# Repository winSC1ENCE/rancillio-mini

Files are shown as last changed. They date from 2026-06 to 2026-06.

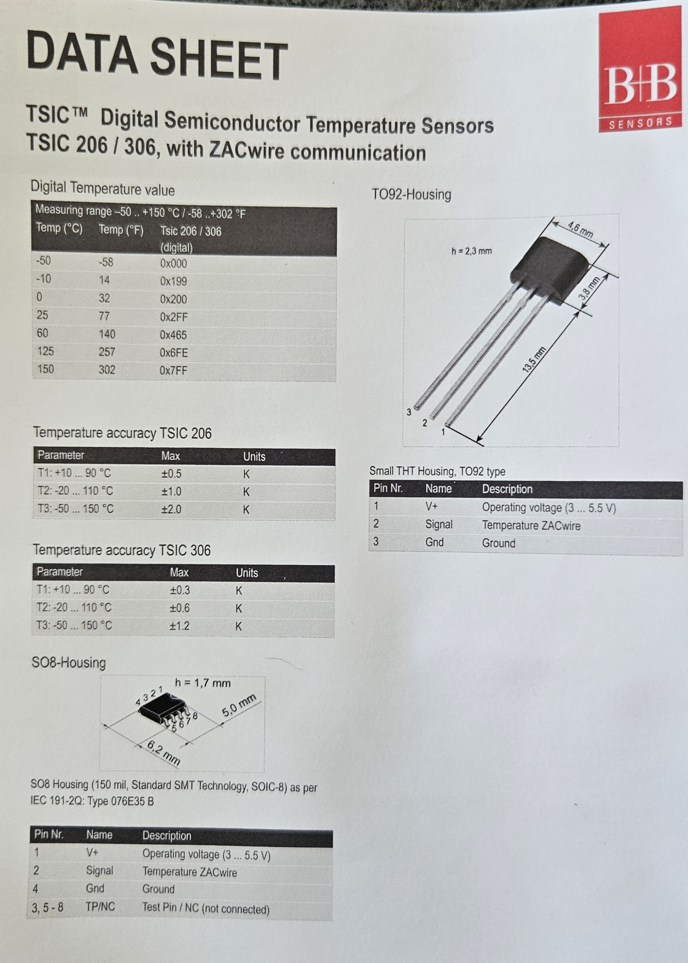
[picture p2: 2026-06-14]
docs/img/temp_sensor_datsheet.jpg

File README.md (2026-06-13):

# CleverCoffee
(formerly Rancilio PID)

<div align="center">

<br>
<a href='https://ko-fi.com/clevercoffee' target='_blank'>Buy Me a Coffee at ko-fi.com</a>
</div>

# About

This project implements a PID controller for stable and accurate temperature control, originally for Rancilio Silvia espresso machines but also includes support for Gaggia and Quickmill machines. Others can easily be added or are already compatible.

Additional features include:

* brew timer
* pre-infusion (reduced initial pressure using a dimmer for the pump)
* brew by weight (using weight cells, no support for external scales yet)
* pressure monitoring
* water level monitoring

The hardware has a small footprint and can easily fit also into most smaller espresso machines. The original wiring of the machine (mostly) remains and is only extended. The machine can be easily reversed to the orignal state after the conversion.

The project has been in active development and supported for 4 years with continuous improvements. Hundreds of machines have been converted to PID control already.

You can find our project website here: [Clever Coffee Website](https://clevercoffee.de).

This software is Open Source: free of charge for you and customizable to your personal needs. 

We recommend you to have a look at the manual before starting a build, you can find the german one [here](https://rancilio-pid.github.io/ranciliopid-handbook/). It is currently being reworked to include all the latest features. The english one is sadly still very outdated but will also be updated soon. 

Our chat for collaboration and questions can be found[here](https://chat.rancilio-pid.de).

Video tutorial on how to flash the firmware (a little outdated but mostly still valid):<br>
https://youtu.be/KZPjisOEcQ4

## Version
ESP8266 Version 3.3.0

## What is possible after installation into your espresso machine? 
 * Control of the brewing temperature with an accuracy of up to +/- 0,1°.
 * Reach the target temperature within 8 to 12 minutes after switching on (you should however wait a bit longer, e.g. 20 min depending on the machine to heat up brew head etc.)
 * **NEW** Control all parameters and see temperature and heater graphs on a web page hosted on the ESP controller
 * PID for steam mode with own parameters and target temperature (can be enabled in the web interface/MQTT or using the steam switch when all features are built in) 
 * Control the brewing time (including pre-infusion) when all features are built in.
 * Integration of a scale function, allows brewing by weight.
 * Integration of a water level sensor.
 * Multiple designs for the display, possibility to integrate further designs easily (including vertical template)
 * **NEW** MQTT (IoT) support to manipulate all important parameters.
 * **NEW** Transition from steam mode to normal mode optimized.
 * Brew switch detection also supported using an optocoupler when using OnlyPID ([details](https://rancilio-pid.github.io/ranciliopid-handbook/de/customization/brueherkennung.html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)).
 * Shot timer adjustable to see the reference time.
 * Support for Siliva E machines: trigger with definable interval for a relay to bypass the Eco function
 * Extended data monitoring via Influxdb/Grafana.
 * Over-The-Air updates of the firmware are possible via Wifi

User feedback and suggestions for further development of the software are most welcome.
You are welcome to help us in our mission to make better espresso :)

Thanks to every single supporter!

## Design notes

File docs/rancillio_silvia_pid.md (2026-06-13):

# Rancillio Silvia PID 

## Original Github Projekt 
- https://github.com/rancilio-pid/clevercoffee

## Platine
- https://manual.rancilio-pid.de/de/platinen/ESP8266.html#pin-belegung-vom-pcb-esp8266
- Ich habe aktuell die Platine für den ESP8266 in der Version Rev 1.2 

## Handbuch
- https://manual.rancilio-pid.de/de/

# Materialliste Aktuell
- Platine Rev 1.2 
- Microcontroller AZ Delivery NodeMCU Amica V2 ESP8266MOD 12-F
- Display AZ Delivery 0.96 Zoll 12C Oled Display 
- Relais E32-0U3 RA 2425-D06
- Netzgerät Mean-Well IA-433 SNT RS 15 5
- Temperatir Sensor TSIC 306  TO92

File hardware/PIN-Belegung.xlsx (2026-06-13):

NodeMCU incl. OLED DISPLAY
 |  |  |  |  |  |  | DISPLAY |  |  |  | TEMP
PINS von Links nach Rechts | 1 | 2 | 3 | 4 | 5 | 6 | 7 | 8 | 9 | 10 | 11 | 12
Beschriftung auf NodeMCU | GND | 5V | 3,3V | GND | CTS | DTR | D1 | D10 | D9 | /RESET | D4 | CHPD
GPIO |  |  |  |  |  |  | GPIO5 | GPIO1 | GPIO3 |  | GPIO2
Funktion |  |  |  |  | USB UART | USB UART | SCL (I2C) CLOCK Display | TxD | RxD
PINS von Links nach Rechts | 1 | 2 | 3 | 4 | 5 | 6 | 7 | 8 | 9 | 10 | 11 | 12
Beschriftung auf NodeMCU | GND | 5V | 3,3V | GND | D2 | D3 | D8 | D7 | D6 | D5 | D0 | A0
GPIO |  |  |  |  | GPIO4 | GPIO0 | GPIO15 | GPIO13 | GPIO12 | GPIO14 | GPIO16
Funktion |  |  |  |  | SDA (I2C) DATA Display | 10k Pull-Up Widerstand und einen Taster nach GND | Muss beim Start Low sein, hat 10k Pull-Down Widerstand | Normaler I/O Pin oder SPI Daten. | Normaler I/O Pin oder SPI Daten. | Normaler I/O Pin oder SPI Takt. | RST (I2C) Display | Analoger Eingang für 0..3,3V
 |  |  |  |  | DISPLAY |  |  | PUMPE | VENTIL | HEATER | DISPLAY | SCHALTER

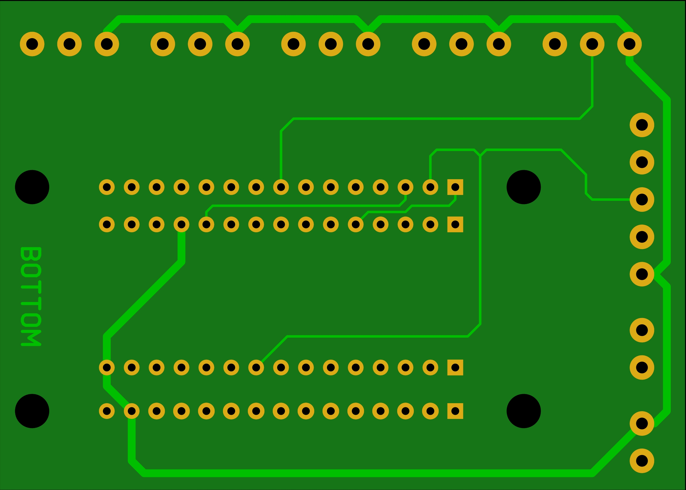
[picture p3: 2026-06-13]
hardware/Platinendesign/Rev_1.2/Ansicht_BOTTOM.JPG

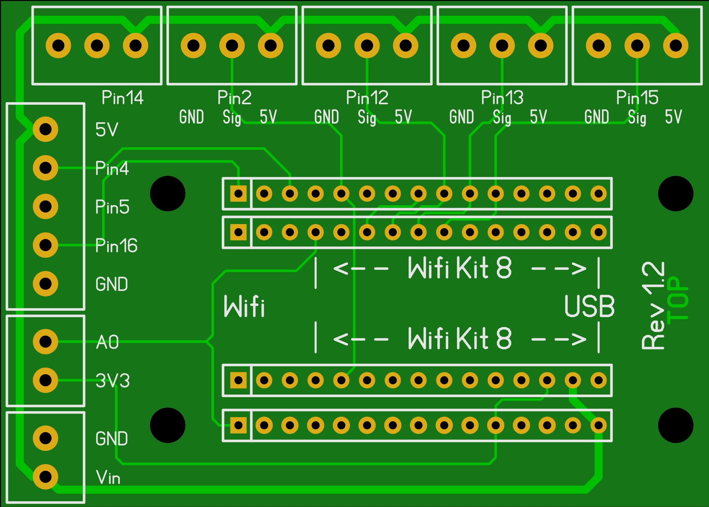
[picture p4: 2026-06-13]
hardware/Platinendesign/Rev_1.2/Ansicht_TOP.JPG

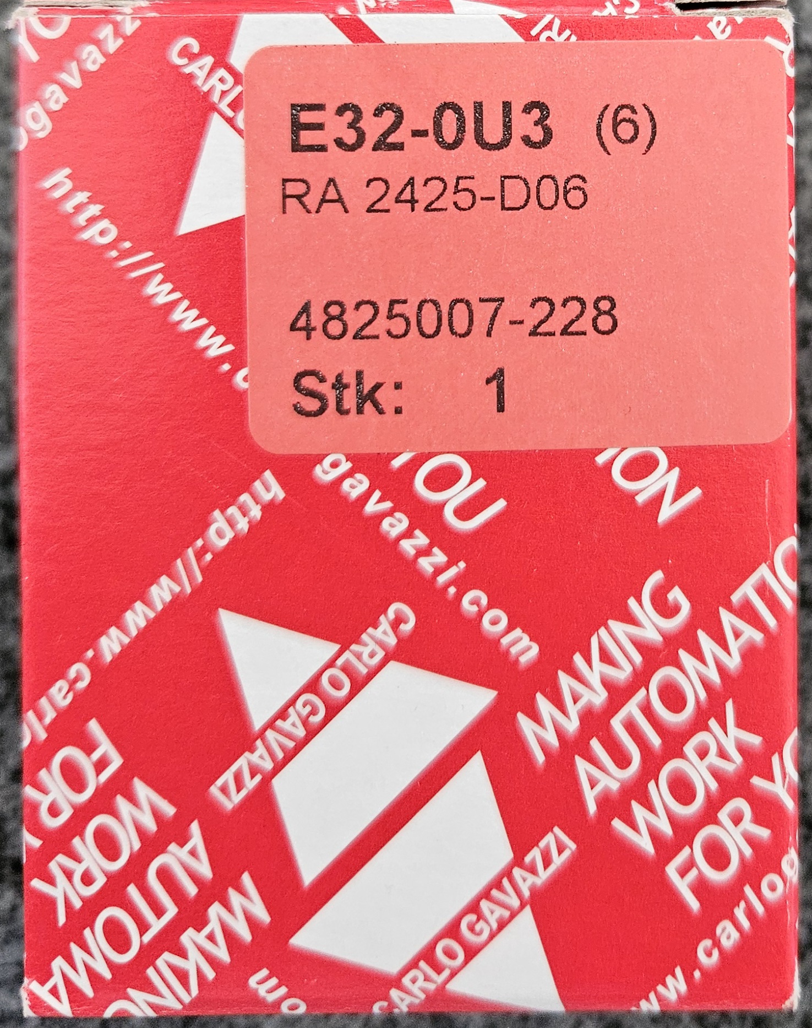
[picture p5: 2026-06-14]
docs/img/relais.jpg

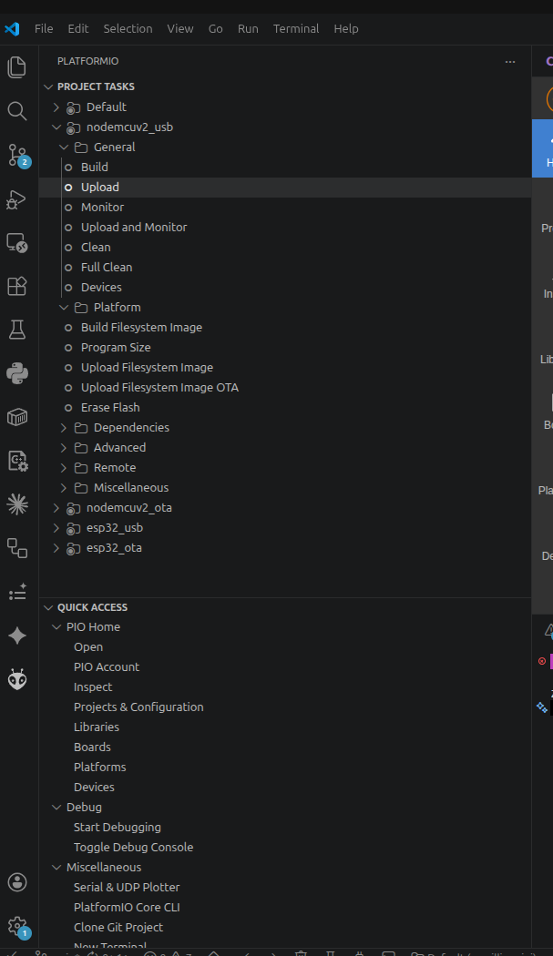
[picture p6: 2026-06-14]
docs/Screenshot From 2026-06-14 00-00-22.png

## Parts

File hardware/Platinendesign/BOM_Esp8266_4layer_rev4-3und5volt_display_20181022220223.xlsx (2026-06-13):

ID | Name | Designator | Footprint | Quantity | Manufacturer Part | Manufacturer | Supplier | Supplier Part | Mounted
1 | DIP-1X15P2.54 | U1,U2,U5,U3 | DIP-1X15P2.54 | 4 | 220S-1*15P H=8.5MM Ytype Gold-plated | Ckmtw | LCSC
2 | PH-2AW | Analog_In,Supply | PH-2AW | 2 | PH-2AW RHOS | BOOMELE | LCSC
3 | PH-4AW | Pin15,Pin13,Pin12,Pin2,Pin14 | PH-4AW | 5 | PH-4AW | BOOMELE | LCSC
4 | PH-5AW | Display | PH-5AW | 1 | PH-5AW | BOOMELE | LCSC

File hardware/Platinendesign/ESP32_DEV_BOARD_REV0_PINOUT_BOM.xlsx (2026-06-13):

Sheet: PIN_Belegung
ESP32-PinOuts für Clevercoffee-PID
GPIO | Input | Output | Notes | Modul | Elektr. Bauteil | GND | 5V | 3,3V | ADC-Version | PCB? | GPIO | Input | Output | Notes | Referenzdesign
0 | pulled up | OK | outputs PWM signal at boot |  |  |  |  |  | ADC2 |  | 0 | pulled up | OK | outputs PWM signal at boot
1 | TX pin | OK | debug output at boot |  |  |  |  |  |  |  | 1 | TX pin | OK | debug output at boot
2 | OK | OK | connected to on-board LED |  |  |  |  |  | ADC2 |  | 2 | OK | OK | connected to on-board LED
3 | OK | RX pin | HIGH at boot | Button | Push Button |  |  | 3,3V |  | nein | 3 | OK | RX pin | HIGH at boot
4 | OK | OK |  | Dampfschalter | Schalter |  |  |  | ADC2 | nein | 4 | OK | OK
5 | OK | OK | outputs PWM signal at boot |  |  |  |  |  |  | nein | 5 | OK | OK | outputs PWM signal at boot
6 | x | x | connected to the integrated SPI flash | n.v. | n.v. | n.v. | n.v. | n.v. | n.v. |  | 6 | x | x | connected to the integrated SPI flash
7 | x | x | connected to the integrated SPI flash | n.v. | n.v. | n.v. | n.v. | n.v. | n.v. |  | 7 | x | x | connected to the integrated SPI flash
8 | x | x | connected to the integrated SPI flash | n.v. | n.v. | n.v. | n.v. | n.v. | n.v. |  | 8 | x | x | connected to the integrated SPI flash
9 | x | x | connected to the integrated SPI flash | n.v. | n.v. | n.v. | n.v. | n.v. | n.v. |  | 9 | x | x | connected to the integrated SPI flash
10 | x | x | connected to the integrated SPI flash | n.v. | wäre ein | n.v. | n.v. | n.v. | n.v. |  | 10 | x | x | connected to the integrated SPI flash
11 | x | x | connected to the integrated SPI flash | n.v. | n.v. | n.v. | n.v. | n.v. | n.v. |  | 11 | x | x | connected to the integrated SPI flash
12 | OK | OK | boot fail if pulled high | Rotary Encoder / Touch | Rotary Encoder Push Button |  |  |  | ADC2 | ja | 12 | OK | OK | boot fail if pulled high
13 | OK | OK |  | Touch (Optional) |  |  |  |  |  | ja | 13 | OK | OK
14 | OK | OK | outputs PWM signal at boot | Rotary Encoder / Touch | Rotary Encoder |  |  | 3,3V | ADC2 | ja | 14 | OK | OK | outputs PWM signal at boot
15 | OK | OK | outputs PWM signal at boot | Rotary Encoder / Touch | Rotary Encoder |  |  |  | ADC2 | ja | 15 | OK | OK | outputs PWM signal at boot
16 | OK | OK |  | Temp. Sensor | TSIC 306 TO92 | GND |  | 3,3V |  | ja | 16 | OK | OK
17 | OK | OK |  | Pumpe | SSR/Relais (SSR bevorzugt) | GND | 5V | 3,3V |  | ja | 17 | OK | OK
18 | OK | OK |  | 3W-Ventil | SSR/Relais (SSR bevorzugt) |  |  |  |  | ja | 18 | OK | OK
19 | OK | OK |  | Heizung | SSR 20A | GND |  |  |  | ja | 19 | OK | OK
21 | OK | OK | SDA | Display / Touch | SDA | GND | 5V |  |  | ja | 21 | OK | OK | SDA
22 | OK | OK | SCL | Display / Touch | SCL |  |  |  |  | ja | 22 | OK | OK | SCL
23 | OK | OK |  | Flowmeter | Digimesa 932-9521-b | GND | 5V | 3,3V |  | ja | 23 | OK | OK
25 | OK | OK |  | E-Trigger | Relais | GND | 5V | 3,3V | ADC2 | ja | 25 | OK | OK
26 | OK | OK |  | Pumpe | Dimmer RobotDyn 6970622932550 |  |  |  | ADC2 | ja | 26 | OK | OK
27 | OK | OK |  | Touch | 2.8 TFT Touch Screen ILI9341Type |  |  |  | ADC2 | ja | 27 | OK | OK
32 | OK | OK |  | Waage | HX711 CLK | GND | 5V |  | ADC1 (Wifi-Input) | ja | 32 | OK | OK
33 | OK | OK |  | Waage | HX711 DAT |  |  | 3,3V | ADC1 (Wifi-Input) | ja | 33 | OK | OK
34 | OK |  | input only - no PWM | Freier GIPO |  | GND |  | 3,3V | ADC1 (Wifi-Input) | ja | 34 | OK |  | input only
35 | OK |  | input only - no PWM | Brühschalter | Schalter | GND |  | 3,3V | ADC1 (Wifi-Input) | ja | 35 | OK |  | input only
36 | OK |  | input only - no PWM | Drucksensor | Druckzelle |  |  |  | ADC1 (Wifi-Input) | ja | 36 | OK |  | input only
39 | OK |  | input only - no PWM | Freier ADC |  |  |  |  | ADC1 (Wifi-Input) | ja | 39 | OK |  | input only
EN |  |  |  | Touch | 2.8 TFT Touch Screen ILI9341Type
Quellen:
ESP32 - GPIO und Anschlussbeschreibungen (https://randomnerdtutorials.com/esp32-pinout-reference-gpios/)
 |  | Touch
 |  | PIN 1
 |  | PIN 2
 |  | PIN 3
 |  | PIN 4
 |  | PIN 5
 |  | PIN 6
 |  | RST | 3V3
 |  | VCC | 5V
 |  | GND

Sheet: BOM
BOM Export
ID | Name | Designator | Footprint | Quantity | Manufacturer Part | Manufacturer | Supplier | Supplier Part | Price | LCSC Assembly | Paste Type
1 | 220uF | C1,C2 | CAP-TH_BD6.3-P2.50-D1.0-FD | 2 | KF0J221ME050A00CV0 | Changzhou Huawei Elec | LCSC | C271304 | 0.0248 | Yes
2 | 100nF | C3,C4,C5,C6 | CAP-TH_L8.5-W5.0-P5.00-D1.2 | 4 | CT4-0805B104K500F3 | FH | LCSC | C84772 | 0.0141 | Yes
3 | E-Trigger | CN1 | CONN-TH_4P-P2.00_PH--4AW | 1 | PH-4AW | BOOMELE | LCSC | C10401 | 0.0085 | Yes | expand
4 | Heizung | CN2 | CONN-TH_PH-2AW | 1 | PH-2AW | CAX | LCSC | C722769 | 0.003545 | Yes | expand
5 | Pumpe/Ventil | CN3,CN15 | CONN-TH_6P-P2.00_PH-6AW | 2 | PH-6AW | BOOMELE | LCSC | C5662 | 0.0126 | Yes | expand
6 | Drucksensor | CN4 | CONN-TH_3P-P2.00_PH-3AK | 1 | PH-3A | Boom Precision Elec | LCSC | C146083 | 0.0108 | Yes | expand
7 | Dampfschalter | CN5 | CONN-TH_3P-P2.00_PH-3AK | 1 | PH-3A | Boom Precision Elec | LCSC | C146083 | 0.0108 | Yes | expand
8 | TSIC | CN6 | CONN-TH_PH-3AW | 1 | PH-3AW | BOOMELE | LCSC | C10400 | 0.0064 | Yes | expand
9 | Display/Touch | CN7 | CONN-TH_PH-5AW | 1 | PH-5AW | BOOMELE | LCSC | C10402 | 0.0105 | Yes | expand
10 | Waage | CN9 | CONN-TH_PH-5AW | 1 | PH-5AW | BOOMELE | LCSC | C10402 | 0.0105 | Yes | expand
11 | 5 Volt input | CN10 | CONN-TH_PH-2AW | 1 | PH-2AW | CAX | LCSC | C722769 | 0.003545 | Yes | expand
12 | Encoder/Touch | CN11 | CONN-TH_PH-5AW | 1 | PH-5AW | BOOMELE | LCSC | C10402 | 0.0105 | Yes | expand
13 | Flowmeter | CN12 | CONN-TH_4P-P2.00_PH-4AK | 1 | PH-4A | Boom Precision Elec | LCSC | C146084 | 0.0126 | Yes | expand
14 | IC2 | CN13 | CONN-TH_4P-P2.00_PH-4AK | 1 | PH-4A | Boom Precision Elec | LCSC | C146084 | 0.0126 | Yes | expand
15 | Brühschalter | CN14 | CONN-TH_3P-P2.00_PH-3AK | 1 | PH-3A | Boom Precision Elec | LCSC | C146083 | 0.0108 | Yes | expand
16 | Header-Female-2.54_1x20 | P4,P5 | HDR-TH_20P-P2.54-V-F | 2 | 2.54mm 1*20P Female header | BOOMELE | LCSC | C50984 | 0.1184 | Yes | expand
17 | 51K | R1,R2 | RES-TH_BD2.4-L6.3-P10.30-D0.6 | 2 | RD 1/4W 51K J T/B A1 | TyoHM | LCSC | C433709 | 0.00561 | Yes | expand
18 | 4.7K | R5,R6 | RES-TH_BD2.2-L6.5-P10.50-D0.6 | 2 | CFR0W4J0472A50 | UniOhm | LCSC | C61297 | 0.0055 | Yes | expand
19 | A2541WV-2X2P | V_CN13_CN7 | HDR-TH_4P-P2.54-V-R2-C2-S2.54_A2541WV-2X2P | 1 | A2541WV-2x2P | Changjiang Connectors | LCSC | C225517 | 0.0755 | Yes | expand
Bestellung
Summe | LCSC Part Number | Beschreibung | Summe2 | x | Bestellt LSCS | Prüfung
30 | C271304 | 220uF | 15 | 2 | 30 | FALSE
60 | C84772 | 100nF | 15 | 4 | 60 | FALSE
30 | C5662 | PH-6AW | 15 | 2 | 50 | FALSE
45 | C10402 | PH-5AW | 15 | 3 | 50 | FALSE
15 | C10401 | PH-4AW | 15 | 1 | 50 | FALSE
15 | C10400 | PH-3AW | 15 | 1 | 50 | FALSE
30 | C722769 | PH-2AW | 15 | 2 | 50 | FALSE
30 | C33478 | PH-6A | 15 | 2 | 50 | FALSE
45 | C2322 | PH-5A | 15 | 3 | 50 | FALSE
45 | C146084 | PH-4A | 15 | 3 | 50 | FALSE
60 | C146083 | PH-3A | 15 | 4 | 100 | FALSE
30 | C2319 | PH-2A | 15 | 2 | 50 | FALSE
30 | C50984 | 2.54mm 1*20P Female header | 15 | 2 | 30 | FALSE
30 | C433709 | 51 K | 15 | 2 | 50 | FALSE
30 | C61297 | 4,7 k | 15 | 2 | 50 | FALSE
15 | C225517 | 2x2 Header | 15 | 1 | 15 | FALSE
30 | C157952 | Housing PH 6 | 15 | 2 | 40 | FALSE
45 | C157953 | Housing PH 5 | 15 | 3 | 50 | FALSE
45 | C111514 | Housing PH 4 | 15 | 3 | 50 | FALSE
60 | C157954 | Housing PH 3 | 15 | 4 | 100 | FALSE
30 | C157955 | Housing PH 2 | 15 | 2 | 50 | FALSE
900 | C8875 | Crimptkontakte | 15 | 60 | 900 | FALSE
15 | C2689176 | Brücken | 15 | 1 | 50 | FALSE

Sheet: Datenblaetter
Einkaufsliste
 |  |  | Datenblatt
Flowmeter | Digimesa | 932-9521-b | https://www.digmesa.com/wp-content/uploads/932-952x_Bxxx_D_20V-2.pdf
Paddle | Alps Alpine | RSA0N11S9002 | https://docs.rs-online.com/453e/0900766b80124572.pdf
SSR 25A | Jotta,
SSR 2x2A | China mit Omron

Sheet: NodeMCUDev4C_Lochraster
Platinenlayout Oberseite |  |  |  |  |  |  |  |  |  |  |  |  |  |  |  |  |  |  |  |  |  |  |  |  |  |  |  |  |  |  |  | Platinenlayout Unterseite
 | A | B | C | D | E | F | G | H | I | J | K | L | M | N | O | P | Q | R | S | T | U | V | W | X | Y | Z | A | B | C | D | E |  | A | B | C | D | E | F | G | H | I | J | K | L | M | N | O | P | Q | R | S | T | U | V | W | X | Y | Z
A |  |  |  |  |  |  |  |  |  |  |  |  |  |  |  |  |  |  |  |  |  |  |  |  |  |  |  |  |  |  |  | A
B |  |  |  |  |  |  |  |  |  |  |  |  |  |  |  |  |  |  |  |  |  |  |  |  |  |  |  |  |  |  |  | B
C |  |  |  |  |  |  |  |  |  |  |  |  |  |  |  |  |  |  |  |  |  |  |  |  |  |  |  |  |  |  |  | C
D |  |  |  |  |  |  |  |  |  |  |  |  |  |  |  |  |  |  |  |  |  |  |  |  |  |  |  |  |  |  |  | D
E |  |  |  |  |  |  |  |  |  |  |  |  |  |  |  |  |  |  |  |  |  |  |  |  |  |  |  |  |  |  |  | E
F |  |  |  |  |  |  |  |  |  |  |  |  |  |  |  |  |  |  |  |  |  |  |  |  |  |  |  |  |  |  |  | F
G |  |  |  |  |  |  |  |  |  |  |  |  |  |  |  |  |  |  |  |  |  |  |  |  |  |  |  |  |  |  |  | G
H |  |  |  |  |  |  |  |  | o | o | o | o | o | o | o | o | o | o | o | o | o | o | o | o | o | o | o |  |  |  |  | H |  |  |  |  | o | o | o | o | o | o | o | o | o | o | o | o | o | o | o | o | o | o | o
I |  |  |  |  |  |  |  |  | 5V | 11 | 10 | 9 | 13 | GND | 12 | 14 | 27 | 26 | 25 | 33 | 32 | 35 | 34 | 39 | 36 | EN | 3.3 |  |  |  |  | I |  |  |  |  | 3.3 | EN | 36 | 39 | 34 | 35 | 32 | 33 | 25 | 26 | 27 | 14 | 12 | GND | 13 | 9 | 10 | 11 | 5V
J |  |  |  |  |  |  |  |  |  |  |  |  |  |  |  |  |  |  |  |  |  |  |  |  |  |  |  |  |  |  |  | J
K |  |  |  |  |  |  |  |  |  |  |  |  |  |  |  |  |  |  |  |  |  |  |  |  |  |  |  |  |  |  |  | K
L |  |  |  |  |  |  |  |  |  |  |  |  |  |  |  |  |  |  |  |  |  |  |  |  |  |  |  |  |  |  |  | L
M |  |  |  |  |  |  |  |  |  |  |  |  |  |  |  |  |  |  |  |  |  |  |  |  |  |  |  |  |  |  |  | M
N |  |  |  |  |  |  |  |  |  |  |  |  |  |  |  |  |  |  |  |  |  |  |  |  |  |  |  |  |  |  |  | N
O |  |  |  |  |  |  |  |  |  |  |  |  |  |  |  |  |  |  |  |  |  |  |  |  |  |  |  |  |  |  |  | O
P |  |  |  |  |  |  |  |  |  |  |  |  |  |  |  |  |  |  |  |  |  |  |  |  |  |  |  |  |  |  |  | P
Q |  |  |  |  |  |  |  |  | 6 | 7 | 8 | 15 | 2 | 0 | 4 | 16 | 17 | 5 | 18 | 19 | GND | 21 | 3 | 1 | 22 | 23 | GND |  |  |  |  | Q |  |  |  |  | GND | 23 | 22 | 1 | 3 | 21 | GND | 19 | 18 | 5 | 17 | 16 | 4 | 0 | 2 | 15 | 8 | 7 | 6
R |  |  |  |  |  |  |  |  | o | o | o | o | o | o | o | o | o | o | o | o | o | o | o | o | o | o | o |  |  |  |  | R |  |  |  |  | o | o | o | o | o | o | o | o | o | o | o | o | o | o | o | o | o | o | o
S |  |  |  |  |  |  |  |  |  |  |  |  |  |  |  |  |  |  |  |  |  |  |  |  |  |  |  |  |  |  |  | S
T |  |  |  |  |  |  |  |  |  |  |  |  |  |  |  |  |  |  |  |  |  |  |  |  |  |  |  |  |  |  |  | T
U |  |  |  |  |  |  |  |  |  |  |  |  |  |  |  |  |  |  |  |  |  |  |  |  |  |  |  |  |  |  |  | U
V |  |  |  |  |  |  |  |  |  |  |  |  |  |  |  |  |  |  |  |  |  |  |  |  |  |  |  |  |  |  |  | V
W |  |  |  |  |  |  |  |  |  |  |  |  |  |  |  |  |  |  |  |  |  |  |  |  |  |  |  |  |  |  |  | W
X |  |  |  |  |  |  |  |  |  |  |  |  |  |  |  |  |  |  |  |  |  |  |  |  |  |  |  |  |  |  |  | X
Y |  |  |  |  |  |  |  |  |  |  |  |  |  |  |  |  |  |  |  |  |  |  |  |  |  |  |  |  |  |  |  | Y
Z |  |  |  |  |  |  |  |  |  |  |  |  |  |  |  |  |  |  |  |  |  |  |  |  |  |  |  |  |  |  |  | Z
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

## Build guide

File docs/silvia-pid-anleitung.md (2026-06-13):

# Rancilio Silvia – PID-Umbau (Individueller Plan für ESP8266 / Rev 1.2)

Diese Anleitung ist speziell auf dein Setup mit der **Rancilio Silvia**, dem **ESP8266 (NodeMCU Amica V2)** und der **CleverCoffee Platine Rev 1.2** zugeschnitten.

**⚠️ WICHTIGER HINWEIS ZUR SOFTWARE-VERSION:**
Laut dem aktuellen CleverCoffee Projekt wird ab **Version 4.0.0** die Entwicklung *ausschließlich für den ESP32* fortgesetzt! Da du einen **ESP8266** verwendest, bist du für die Firmware auf eine ältere Version (z. B. v3.x.x) angewiesen. Die neuen Features wie Web-Flasher oder BLE-Waagen aus v4.0.0 sind mit deinem Microcontroller leider nicht kompatibel. Du musst die Firmware klassisch über **VSCode + PlatformIO** flashen.

---

## 🛠 Deine Hardware-Materialliste

| Komponente | Spezifikation / Modell | Funktion im Umbau |
|---|---|---|
| **Platine** | CleverCoffee PCB **Rev 1.2** | Trägerplatine (Shield), verteilt Spannung & Signale. |
| **Mikrocontroller** | AZ-Delivery NodeMCU Amica V2 (ESP8266MOD 12-F) | Das „Gehirn“: Liest den Sensor, regelt die Heizung per PID, stellt WLAN bereit. |
| **Display** | AZ-Delivery 0,96″ I²C OLED | Anzeige von Ist-/Soll-Temperatur und Status an der Maschine. |
| **Relais (SSR)** | SSR E32-0U3 RA 2425-D06 | Schaltet die 230V-Heizung sicher per 5V-Steuersignal vom ESP. |
| **Netzteil** | Mean-Well IA-433 SNT RS-15-5 (5 V) | Versorgt ESP, Platine und das OLED-Display mit 5V Gleichstrom. |
| **Sensor** | TSIC 306 (TO-92) | Misst hochpräzise die aktuelle Boilertemperatur. |

**Referenzen:**
- [CleverCoffee Handbuch (Deutsch)](https://manual.rancilio-pid.de/de/)
- [Pinbelegung Platine Rev 1.2 für ESP8266](https://manual.rancilio-pid.de/de/platinen/ESP8266.html)

---

## ⚠️ Schritt 1 – Sicherheit zuerst (Lebenswichtig!)

Du arbeitest mit **230 V Netzspannung** und einem **~1100 W Heizelement**. Fehler können lebensgefährlich sein!

- **Netzstecker ziehen** und Maschine vollständig abkühlen lassen, bevor du sie öffnest.
- Arbeite **niemals** an der Maschine, solange sie am Netz hängt.
- Der **Sicherheits-/Übertemperaturthermostat (Klixon)** der Silvia **muss in der Heizung in Reihe bleiben**. Er ist die Notabschaltung. Niemals überbrücken!
- Der **Brüh-Thermostat (Bimetall, i.d.R. 100°C)** wird durch das SSR ersetzt – die Temperaturregelung übernimmt ab jetzt der ESP.
- Alle Adern mit 230V müssen korrekt gecrimpt (Aderendhülsen oder Flachstecker) und isoliert werden.
- Wenn du dir bei der 230-V-Verdrahtung unsicher bist: **Elektrofachkraft hinzuziehen.**

---

## 💻 Schritt 2 – Firmware vorbereiten und ESP8266 flashen

Da Version 4.0 den ESP8266 nicht mehr unterstützt, musst du eine Version aus der **3.x.x Serie** (in deinem Fall **v3.3.0**) installieren.

1. **Software installieren**: Lade dir Visual Studio Code (VSCode) und die Erweiterung **PlatformIO** herunter.
2. **Quellcode laden**: Lade dir den Quellcode einer v3-Version als ZIP von der GitHub-Seite herunter und entpacke ihn.
3. Öffne den entpackten Ordner in VSCode (PlatformIO erkennt das Projekt automatisch).
4. **Konfigurationsdatei anpassen**: Kopiere die `userConfig_sample.h` zu `userConfig.h`. Setze dort die für dich passenden Werte:
   - **WLAN-Zugangsdaten (Wichtig für v3.3.0!):** Trage bei `WIFI_SSID` und `WIFI_PASS` die Daten für dein Heimnetzwerk ein. Der WiFi-Manager wurde in dieser Version entfernt, eine Konfiguration per Weboberfläche ist beim ersten Start nicht mehr möglich.
   - **Temperatursensor**: Setze `TEMPSENSOR` auf `2` für den TSIC.
   - **Display**: Setze `OLED_DISPLAY` auf `2` für das SSD1306 0,96" Display.
   - Prüfe auch die weiteren Einstellungen wie `MACHINEID` und passe sie bei Bedarf an.
5. **ESP flashen**: Verbinde den AZ-Delivery NodeMCU per Micro-USB mit dem PC und klicke in PlatformIO auf "Upload".

> *Tipp: Teste den NodeMCU + Platine + OLED kurz am USB-Kabel (vor dem Einbau in die Maschine). Wenn das OLED etwas anzeigt, war das Flashen erfolgreich. Der ESP wird versuchen, sich direkt mit dem von dir konfigurierten WLAN zu verbinden.*

**Referenzen:**
- CleverCoffee GitHub Releases (für v3.x.x)
- Anleitung: Software installieren (CleverCoffee Handbuch) [11]
- Download Visual Studio Code
- PlatformIO IDE für VSCode

---

## 🧩 Schritt 3 – Platine Rev 1.2 bestücken

1. **NodeMCU aufstecken**: Achte darauf, dass der Micro-USB Anschluss in die Richtung zeigt, die auf der Rev 1.2 Platine markiert ist (Pin-1 Aufdruck beachten).
2. **OLED anschließen**: Verbinde das Display an den I²C-Anschluss der Platine. *Achtung: Bei AZ-Delivery sind oft VCC und GND sowie SDA und SCL vertauscht! Überprüfe die Beschriftung des Displays exakt mit der Beschriftung auf der Platine.*
3. **Klemmen identifizieren**: Mache dich mit den Anschlüssen für das Relais (SSR-Steuerung), den Sensor (TSIC) und den 5V Eingang vertraut. Siehe dazu den Platinen-Guide.

**Referenzen:**
- Pinbelegung Platine Rev 1.2 für ESP8266
- Allgemeiner Aufbau der Hardware (CleverCoffee Handbuch) [17]

---

## 🔧 Schritt 4 – Maschine öffnen & Dokumentieren

1. Stecker gezogen, Maschine kalt.
2. Wassertank entnehmen, obere Abdeckung abschrauben, Gehäuse öffnen.
3. **Fotos machen!** Fotografiere die Werksverdrahtung am Boiler und den Thermostaten, bevor du Kabel abziehst.
4. Finde den **Brüh-Thermostat** (wird stillgelegt/überbrückt) und den **Sicherheitsthermostat** (bleibt erhalten!).

---

## 🌡️ Schritt 5 – Temperatursensor (TSIC 306) anbringen

Der Sensor benötigt drei Verbindungen: GND, VCC (3,3V) und Signal.

1. Prüfe das Datenblatt des TSIC 306 (TO-92), um die 3 Beinchen korrekt zuzuordnen.
2. Befestige den Sensor mit etwas **Wärmeleitpaste** am Kessel (z. B. unter der Klammer des alten Brüh-Thermostats oder mit einer passenden Schraube).
3. Verlege ein 3-adriges, hitzebeständiges Kabel (z. B. Silikonlitze) von der Platine zum Sensor.
4. Schließe die Adern an die "TSIC" Pins der Platine (GND / 3.3V / SIG) an.

**Referenzen:**
- Datenblatt TSIC 306 (Beispiel) [14]
- Anleitung: Temperatursensor anschließen (CleverCoffee Handbuch)
---

## ⚡ Schritt 6 – Heizung (SSR E32-0U3) & Netzteil (Mean-Well RS-15-5)

**Das SSR (E32-0U3 RA 2425-D06):**
1. **Lastseite (230 V):** Trenne die beiden Kabel, die an den Brüh-Thermostat gehen. Diese werden an die Last-Klemmen des SSR angeschlossen. *Der Stromkreislauf verläuft nun über das SSR zur Heizung und den Sicherheitsthermostat.*
2. **Steuerseite (DC 5V):** Verbinde den Schaltausgang der Platine Rev 1.2 mit dem Steuereingang (+ und -) des SSR. Polung beachten!
3. Platziere das SSR so, dass es Wärme an ein Metallteil des Gehäuses abgeben kann.

**Das Netzteil (Mean-Well IA-433 SNT RS-15-5):**
1. **230 V Eingang:** Klemme Phase (L) und Nullleiter (N) parallel an den Netzanschluss der Maschine, **nach** dem Hauptschalter, damit der PID nur an ist, wenn die Maschine läuft. Schließe auch die Erdung (PE) an das Netzteil an.
2. **5 V Ausgang:** Verbinde V+ und V- mit dem **5V In** Terminal der Rev 1.2 Platine. Prüfe die Spannung idealerweise vorher kurz mit einem Multimeter (sollte bei ca. 5.0V liegen).

**Referenzen:**
- Schaltpläne (CleverCoffee Handbuch) [24]
- Anleitung: SSR anschließen (CleverCoffee Handbuch)
- Datenblatt Mean-Well RS-15 Serie [13]

---

## 📦 Schritt 7 – Endmontage & Erster Start

1. Fixiere Platine, SSR und das Mean-Well Netzteil sicher im Gehäuse. Achte auf genügend Abstand zum heißen Boiler (Hitze kann das Netzteil oder den ESP beschädigen).
2. Platziere das OLED-Display so, dass es von außen gut ablesbar ist.
3. **Erster Start (mit Wasser, Boiler voll!):** Stecker rein, Hauptschalter umlegen.
   - Das OLED sollte aufleuchten und die aktuelle Kesseltemperatur anzeigen.
   - Der ESP verbindet sich direkt mit dem in `userConfig.h` eingetragenen WLAN. Du musst die IP-Adresse des Geräts (z.B. über die Weboberfläche deines Routers) herausfinden, um auf das Web-Interface zuzugreifen.
4. **Heiz-Test & PID Tuning:** Öffne das Web-Interface über die IP-Adresse der Maschine und stelle einen Soll-Wert (z. B. 95°C) ein. Beobachte, ob das SSR heizt und die Temperatur wie erwartet ansteigt und sich stabilisiert. Falls die Temperatur über das Ziel hinausschießt, musst du die PID-Werte im Web-Interface anpassen (siehe Community-Empfehlungen für die Silvia).

**Referenzen:**
- Anleitung: PID-Werte einstellen (CleverCoffee Handbuch) [19]
- CleverCoffee Discord Community (für Hilfe & Austausch)

---

## ✅ Checkliste vor dem ersten Espresso

- [ ] Sicherheitsthermostat ist in Reihe verblieben und nicht überbrückt?
- [ ] ESP8266 wurde mit einer v3.x.x Firmware (nicht v4.0.0) erfolgreich geflasht?
- [ ] SSR leuchtet beim Heizen auf und schaltet am Soll-Wert zuverlässig ab?
- [ ] Temperaturanzeige ist plausibel (startet bei ~20-25°C, wenn Maschine kalt ist)?
- [ ] Alle 230V Kontakte sind fest, fachgerecht gecrimpt und vollständig isoliert?

*Viel Erfolg und guten Espresso! ☕*

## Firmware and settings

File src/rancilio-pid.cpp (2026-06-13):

/**
 * @file rancilio-pid.cpp
 *
 * @brief Main sketch
 *
 * @version 3.3.0 Master
 */

// Firmware version
#define FW_VERSION    3
#define FW_SUBVERSION 3
#define FW_HOTFIX     0

#define FW_BRANCH     "ESP8222-MASTER"

// User Config
#include "userConfig.h"         // needs to be configured by the user

// Libraries
#include <ArduinoOTA.h>
#if TOF == 1
    #include <Adafruit_VL53L0X.h>   // for ToF Sensor
#endif
#if TEMPSENSOR == 1
    #include <DallasTemperature.h>  // Library for dallas temp sensor
#endif

#include <InfluxDbClient.h>
#include <PubSubClient.h>
#include <U8g2lib.h>            // i2c display
#include "TSIC.h"               // old library for TSIC temp sensor
#include <ZACwire.h>            // new TSIC bus library
#include "PID_v1.h"             // for PID calculation

// Includes
#include "hardware.h"           // pinmapping esp8266 or esp32
#include "icon.h"               // user icons for display
#include "languages.h"          // for language translation
#include "Storage.h"
#include "ISR.h"
#include "debugSerial.h"
#include "rancilio-pid.h"

#if defined(ESP32)
    #include <os.h>
    hw_timer_t *timer = NULL;
#endif

#if OLED_DISPLAY == 3
#include <SPI.h>
#endif

#if (BREWMODE == 2 || ONLYPIDSCALE == 1)
    #include <HX711_ADC.h>
#endif

// Version of userConfig need to match, checked by preprocessor
#if (FW_VERSION != USR_FW_VERSION) || \
    (FW_SUBVERSION != USR_FW_SUBVERSION) || \
    (FW_HOTFIX != USR_FW_HOTFIX)
    #error Version of userConfig file and rancilio-pid.cpp need to match!
#endif

MACHINE machine = (enum MACHINE)MACHINEID;

#define HIGH_ACCURACY

#include "PeriodicTrigger.h"
PeriodicTrigger writeDebugTrigger(5000);  // returns true every 5000 ms
PeriodicTrigger logbrew(500);

enum MachineState {
    kInit = 0,
    kColdStart = 10,
    kBelowSetPoint = 19,
    kPidNormal = 20,
    kBrew = 30,
    kShotTimerAfterBrew = 31,
    kBrewDetectionTrailing = 35,
    kSteam = 40,
    kCoolDown = 45,
    kBackflush = 50,
    kEmergencyStop = 80,
    kPidOffline = 90,
    kSensorError = 100,
    kEepromError = 110,
};

MachineState machineState = kInit;
int machinestatecold = 0;
unsigned long machinestatecoldmillis = 0;
MachineState lastmachinestate = kInit;
int lastmachinestatepid = -1;

// Definitions below must be changed in the userConfig.h file
int connectmode = CONNECTMODE;

int offlineMode = 0;
const int OnlyPID = ONLYPID;
const int TempSensor = TEMPSENSOR;
const int brewDetectionMode = BREWDETECTION;
const int triggerType = TRIGGERTYPE;
const int VoltageSensorType = VOLTAGESENSORTYPE;
const boolean ota = OTA;
int BrewMode = BREWMODE;

// Display
uint8_t oled_i2c = OLED_I2C;

// ToF Sensor
#if TOF == 1
Adafruit_VL53L0X lox = Adafruit_VL53L0X();
int calibration_mode = CALIBRATION_MODE;
uint8_t tof_i2c = TOF_I2C;
int water_full = WATER_FULL;
int water_empty = WATER_EMPTY;
unsigned long previousMillisTOF;         // initialisation at the end of init()
const unsigned long intervalTOF = 5000;  // ms
double distance;
double percentage;
#endif

// WiFi
const unsigned long wifiConnectionDelay = WIFICONNECTIONDELAY;
const unsigned int maxWifiReconnects = MAXWIFIRECONNECTS;
const char *hostname = HOSTNAME;
const char *ssid = WIFI_SSID;
const char *pass = WIFI_PASS;
unsigned long lastWifiConnectionAttempt = millis();
unsigned int wifiReconnects = 0;  // actual number of reconnects

// OTA
const char *OTAhost = OTAHOST;
const char *OTApass = OTAPASS;

// Backflush values
const unsigned long fillTime = FILLTIME;
const unsigned long flushTime = FLUSHTIME;
int maxflushCycles = MAXFLUSHCYCLES;

// InfluxDB Client
InfluxDBClient influxClient(INFLUXDB_URL, INFLUXDB_DB_NAME);
Point influxSensor("machineState");
const unsigned long intervalInflux = INFLUXDB_INTERVAL;
unsigned long previousMillisInflux;  // initialisation at the end of init()

// Voltage Sensor
unsigned long previousMillisVoltagesensorreading = millis();
const unsigned long intervalVoltagesensor = 200;
int VoltageSensorON, VoltageSensorOFF;

// QuickMill thermoblock steam-mode (only for BREWDETECTION = 3)
const int maxBrewDurationForSteamModeQM_ON = 200;   // if brewtime is shorter steam-mode starts
const int minPVSOffTimedForSteamModeQM_OFF = 1500;  // if PVS-off-time is longer steam-mode ends
unsigned long timePVStoON = 0;      // time pinvoltagesensor switched to ON
unsigned long lastTimePVSwasON = 0; // last time pinvoltagesensor was ON
bool steamQM_active = false;        // steam-mode is active
bool brewSteamDetectedQM = false;   // brew/steam detected, not sure yet what it is
bool coolingFlushDetectedQM = false;

// Pressure sensor
#if (PRESSURESENSOR == 1)   // Pressure sensor connected
    int offset = OFFSET;
    int fullScale = FULLSCALE;
    int maxPressure = MAXPRESSURE;
    float inputPressure = 0;
    const unsigned long intervalPressure = 200;
    unsigned long previousMillisPressure;  // initialisation at the end of init()
#endif

// Method forward declarations
bool mqtt_publish(const char *reading, char *payload);
void setSteamMode(int steamMode);
void setPidStatus(int pidStatus);
void setBackflush(int backflush);
void setNormalPIDTunings();
void setBDPIDTunings();
void loopcalibrate();
void looppid();
void printMachineState();
char const* machinestateEnumToString(MachineState machineState);
void initSteamQM();
boolean checkSteamOffQM();
void writeSysParamsToMQTT(void);
char *number2string(double in);
char *number2string(float in);
char *number2string(int in);
char *number2string(unsigned int in);
float filterPressureValue(float input);

// system parameters
uint8_t pidON = 0;                 // 1 = control loop in closed loop
double brewSetPoint = SETPOINT;
double brewTempOffset = TEMPOFFSET;
double setPoint = brewSetPoint;
double steamSetPoint = STEAMSETPOINT;
uint8_t usePonM = 0;               // 1 = use PonM for cold start PID, 0 = use normal PID for cold start
double steamKp = STEAMKP;
double startKp = STARTKP;
double startTn = STARTTN;
double aggKp = AGGKP;
double aggTn = AGGTN;
double aggTv = AGGTV;
double aggIMax = AGGIMAX;
double brewtime = BREW_TIME;                        // brewtime in s
double preinfusion = PRE_INFUSION_TIME;             // preinfusion time in s
double preinfusionpause = PRE_INFUSION_PAUSE_TIME;  // preinfusion pause time in s
double weightSetpoint = SCALE_WEIGHTSETPOINT;

// PID - values for offline brew detection
uint8_t useBDPID = 0;
double aggbKp = AGGBKP;
double aggbTn = AGGBTN;
double aggbTv = AGGBTV;

#if aggbTn == 0
    double aggbKi = 0;
#else
    double aggbKi = aggbKp / aggbTn;
#endif

double aggbKd = aggbTv * aggbKp;
double brewtimesoftware = BREW_SW_TIME;  // use userConfig time until disabling BD PID
double brewSensitivity = BREWSENSITIVITY;  // use userConfig brew detection sensitivity

// system parameter EEPROM storage wrappers (current value as pointer to variable, minimum, maximum, optional storage ID)
SysPara<double> sysParaPidKpStart(&startKp, PID_KP_START_MIN, PID_KP_START_MAX, STO_ITEM_PID_KP_START);
SysPara<double> sysParaPidTnStart(&startTn, PID_TN_START_MIN, PID_TN_START_MAX, STO_ITEM_PID_TN_START);
SysPara<double> sysParaPidKpReg(&aggKp, PID_KP_REGULAR_MIN, PID_KP_REGULAR_MAX, STO_ITEM_PID_KP_REGULAR);
SysPara<double> sysParaPidTnReg(&aggTn, PID_TN_REGULAR_MIN, PID_TN_REGULAR_MAX, STO_ITEM_PID_TN_REGULAR);
SysPara<double> sysParaPidTvReg(&aggTv, PID_TV_REGULAR_MIN, PID_TV_REGULAR_MAX, STO_ITEM_PID_TV_REGULAR);
SysPara<double> sysParaPidIMaxReg(&aggIMax, PID_I_MAX_REGULAR_MIN, PID_I_MAX_REGULAR_MAX, STO_ITEM_PID_I_MAX_REGULAR);
SysPara<double> sysParaPidKpBd(&aggbKp, PID_KP_BD_MIN, PID_KP_BD_MAX, STO_ITEM_PID_KP_BD);
SysPara<double> sysParaPidTnBd(&aggbTn, PID_TN_BD_MIN, PID_KP_BD_MAX, STO_ITEM_PID_TN_BD);
SysPara<double> sysParaPidTvBd(&aggbTv, PID_TV_BD_MIN, PID_TV_BD_MAX, STO_ITEM_PID_TV_BD);
SysPara<double> sysParaBrewSetPoint(&brewSetPoint, BREW_SETPOINT_MIN, BREW_SETPOINT_MAX, STO_ITEM_BREW_SETPOINT);
SysPara<double> sysParaTempOffset(&brewTempOffset, BREW_TEMP_OFFSET_MIN, BREW_TEMP_OFFSET_MAX, STO_ITEM_BREW_TEMP_OFFSET);
SysPara<double> sysParaBrewTime(&brewtime, BREW_TIME_MIN, BREW_TIME_MAX, STO_ITEM_BREW_TIME);
SysPara<double> sysParaBrewSwTime(&brewtimesoftware, BREW_SW_TIME_MIN, BREW_SW_TIME_MAX, STO_ITEM_BREW_SW_TIME);
SysPara<double> sysParaBrewThresh(&brewSensitivity, BD_THRESHOLD_MIN, BD_THRESHOLD_MAX, STO_ITEM_BD_THRESHOLD);
SysPara<double> sysParaPreInfTime(&preinfusion, PRE_INFUSION_TIME_MIN, PRE_INFUSION_TIME_MAX, STO_ITEM_PRE_INFUSION_TIME);
SysPara<double> sysParaPreInfPause(&preinfusionpause, PRE_INFUSION_PAUSE_MIN, PRE_INFUSION_PAUSE_MAX, STO_ITEM_PRE_INFUSION_PAUSE);
SysPara<double> sysParaWeightSetPoint(&weightSetpoint, WEIGHTSETPOINT_MIN, WEIGHTSETPOINT_MAX, STO_ITEM_WEIGHTSETPOINT);
SysPara<double> sysParaPidKpSteam(&steamKp, PID_KP_STEAM_MIN, PID_KP_STEAM_MAX, STO_ITEM_PID_KP_STEAM);
SysPara<double> sysParaSteamSetPoint(&steamSetPoint, STEAM_SETPOINT_MIN, STEAM_SETPOINT_MAX, STO_ITEM_STEAM_SETPOINT);
SysPara<uint8_t> sysParaPidOn(&pidON, 0, 1, STO_ITEM_PID_ON);
SysPara<uint8_t> sysParaUsePonM(&usePonM, 0, 1, STO_ITEM_PID_START_PONM);
SysPara<uint8_t> sysParaUseBDPID(&useBDPID, 0, 1, STO_ITEM_USE_BD_PID);

// Other variables
int relayON, relayOFF;           // used for relay trigger type. Do not change!
boolean coldstart = true;        // true = Rancilio started for first time
boolean emergencyStop = false;   // Emergency stop if temperature is too high
double EmergencyStopTemp = 120;  // Temp EmergencyStopTemp
float inX = 0, inY = 0, inOld = 0, inSum = 0; // used for filterPressureValue()
int signalBars = 0;              // used for getSignalStrength()
boolean brewDetected = 0;
boolean setupDone = false;
int backflushON = 0;             // 1 = backflush mode active
int flushCycles = 0;             // number of active flush cycles
int backflushState = 10;         // counter for state machine

// Moving average for software brew detection
double tempRateAverage = 0;             // average value of temp values
double tempChangeRateAverageMin = 0;
unsigned long timeBrewDetection = 0;
int isBrewDetected = 0;                 // flag is set if brew was detected
bool movingAverageInitialized = false;  // flag set when average filter is initialized, also used for sensor check

// Brewing, 1 = Normal Preinfusion , 2 = Scale & Shottimer = 2
#include "brewscaleini.h"

// Sensor check
boolean sensorError = false;
int error = 0;
int maxErrorCounter = 10;        // depends on intervaltempmes* , define max seconds for invalid data

// PID controller
unsigned long previousMillistemp;    // initialisation at the end of init()
const unsigned long intervaltempmestsic = 400;
const unsigned long intervaltempmesds18b20 = 400;
int pidMode = 1;    // 1 = Automatic, 0 = Manual

double setPointTemp;
double previousInput = 0;

// Variables to hold PID values (Temp input, Heater output)
double temperature, pidOutput;
int steamON = 0;
int steamFirstON = 0;

#if startTn == 0
    double startKi = 0;
#else
    double startKi = startKp / startTn;
#endif

#if aggTn == 0
    double aggKi = 0;
#else
    double aggKi = aggKp / aggTn;
#endif

double aggKd = aggTv * aggKp;

// Timer - ISR for PID calculation and heat relay output
#include "ISR.h"

PID bPID(&temperature, &pidOutput, &setPoint, aggKp, aggKi, aggKd, 1, DIRECT);

// Dallas temp sensor
#if TEMPSENSOR == 1
    OneWire oneWire(PINTEMPSENSOR);         // Setup a OneWire instance to communicate with OneWire
                                            // devices (not just Maxim/Dallas temperature ICs)
    DallasTemperature sensors(&oneWire);
    DeviceAddress sensorDeviceAddress;      // arrays to hold device address
#endif

// TSIC 306 temp sensor
#if (PINTEMPSENSOR == 16 && TEMPSENSOR == 2 && defined(ESP8266))
    TSIC Sensor1(PINTEMPSENSOR);            // only Signal pin, VCC pin unused by default
#else
    ZACwire Sensor2(PINTEMPSENSOR, 306);    // set pin to receive signal from the TSic 306
#endif


// MQTT
WiFiClient net;
PubSubClient mqtt(net);
const char *mqtt_server_ip = MQTT_SERVER_IP;
const int mqtt_server_port = MQTT_SERVER_PORT;
const char *mqtt_username = MQTT_USERNAME;
const char *mqtt_password = MQTT_PASSWORD;
const char *mqtt_topic_prefix = MQTT_TOPIC_PREFIX;
char topic_will[256];
char topic_set[256];
unsigned long lastMQTTConnectionAttempt = millis();
unsigned int MQTTReCnctFlag;
unsigned int MQTTReCnctCount = 0;
unsigned long previousMillisMQTT;           // initialised at the end of init()
const unsigned long intervalMQTT = 5000;

enum MQTTSettableType {
    tUInt8,
    tDouble
};

struct mqttVars_t {
    String mqttParamName;
    MQTTSettableType type;
    int minValue;
    int maxValue;
    void *mqttVarPtr;
};
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
void loop() {
#if TOF == 1
    if (calibration_mode == 1) {
        loopcalibrate();
    } else {
        looppid();
    }
#else
    looppid();
#endif

}

#if TOF == 1
/**
 * @brief ToF sensor calibration mode
 */
void loopcalibrate() {
    // Deactivate PID
    if (pidMode == 1) {
        pidMode = 0;
        bPID.SetMode(pidMode);
        pidOutput = 0;
    }

    digitalWrite(PINHEATER, LOW);   // Stop heating to be on the safe side ...

    unsigned long currentMillisTOF = millis();

    if (currentMillisTOF - previousMillisTOF >= intervalTOF) {
        previousMillisTOF = millis();
        VL53L0X_RangingMeasurementData_t measure;   // TOF Sensor measurement
        lox.rangingTest(&measure, false);           // pass in 'true' to get debug data printout!
        distance = measure.RangeMilliMeter;         // write new distence value to 'distance'
        debugPrintf("%d mm\n", distance);

        #if OLED_DISPLAY != 0
            displayDistance(distance);
        #endif
    }
}
#endif

void looppid() {
    // Only do Wifi stuff, if Wifi is connected
    if (WiFi.status() == WL_CONNECTED && offlineMode == 0) {
        if (MQTT == 1) {
            checkMQTT();
            writeSysParamsToMQTT();

            if (mqtt.connected() == 1) {
                mqtt.loop();
            }
        }

        ArduinoOTA.handle();  // For OTA

        // Disable interrupt if OTA is starting, otherwise it will not work
        ArduinoOTA.onStart([]() {
            disableTimer1();
            digitalWrite(PINHEATER, LOW);  // Stop heating
        });

        ArduinoOTA.onError([](ota_error_t error) { enableTimer1(); });

        // Enable interrupts if OTA is finished
        ArduinoOTA.onEnd([]() { enableTimer1(); });

        wifiReconnects = 0;  // reset wifi reconnects if connected
    } else {
        checkWifi();
    }

    #if TOF != 0
        unsigned long currentMillisTOF = millis();

        if (currentMillisTOF - previousMillisTOF >= intervalTOF) {
            previousMillisTOF = millis();
            VL53L0X_RangingMeasurementData_t measure;   // TOF Sensor measurement
            lox.rangingTest(&measure, false);           // pass in 'true' to get debug data printout!
            distance = measure.RangeMilliMeter;         // write new distence value to 'distance'

            if (distance <= 1000) {
                percentage = (100.00 / (water_empty - water_full)) * (water_empty - distance);  // calculate percentage of waterlevel
                debugPrintf("%d\n", percentage);
            }
        }
    #endif

    refreshTemp();        // update temperature values
    testEmergencyStop();  // test if temp is too high
    bPID.Compute();       // the variable pidOutput now has new values from PID (will be written to heater pin in ISR.cpp)

    if ((millis() - lastTempEvent) > tempEventInterval) {
        //send temperatures to website endpoint
        sendTempEvent(temperature, brewSetPoint, pidOutput);
        lastTempEvent = millis();

        #if VERBOSE
        if (pidON) {
            debugPrintf("Current PID mode: %s\n", bPID.GetPonE() ? "PonE" : "PonM");

            //P-Part
            debugPrintf("Current PID input error: %f\n", bPID.GetInputError());
            debugPrintf("Current PID P part: %f\n", bPID.GetLastPPart());
            debugPrintf("Current PID kP: %f\n", bPID.GetKp());
            //I-Part
            debugPrintf("Current PID I sum: %f\n", bPID.GetLastIPart());
            debugPrintf("Current PID kI: %f\n", bPID.GetKi());
            //D-Part
            debugPrintf("Current PID diff'd input: %f\n", bPID.GetDeltaInput());
            debugPrintf("Current PID D part: %f\n", bPID.GetLastDPart());
            debugPrintf("Current PID kD: %f\n", bPID.GetKd());

            //Combined PID output
            debugPrintf("Current PID Output: %f\n\n", pidOutput);
            debugPrintf("Current Machinestate: %s\n\n", machinestateEnumToString(machineState));
            debugPrintf("timeBrewed %f\n", timeBrewed);
            debugPrintf("brewtimesoftware %f\n", brewtimesoftware);
            debugPrintf("isBrewDetected %i\n", isBrewDetected);
            debugPrintf("brewDetectionMode %i\n", brewDetectionMode);
        }
        #endif
    }

    #if (BREWMODE == 2 || ONLYPIDSCALE == 1)
        checkWeight();  // Check Weight Scale in the loop
    #endif

    #if (PRESSURESENSOR == 1)
        checkPressure();
    #endif

    brew();                  // start brewing if button pressed
    checkSteamON();          // check for steam
    setEmergencyStopTemp();
    checkpowerswitch();
    handleMachineState();      // update machineState
    tempLed();

    if (INFLUXDB == 1  && offlineMode == 0 ) {
        sendInflux();
    }

    if (ETRIGGER == 1) {  // E-Trigger active then void Etrigger()
        handleETrigger();
    }

    #if (ONLYPIDSCALE == 1)  // only by shottimer 2, scale
        shottimerscale();
    #endif

    // Check if PID should run or not. If not, set to manual and force output to zero
#if OLED_DISPLAY != 0
    unsigned long currentMillisDisplay = millis();
    if (currentMillisDisplay - previousMillisDisplay >= 100) {
        displayShottimer();
    }
    if (currentMillisDisplay - previousMillisDisplay >= intervalDisplay) {
        previousMillisDisplay = currentMillisDisplay;
    #if DISPLAYTEMPLATE < 20  // not using vertical template
        Displaymachinestate();
    #endif
        printScreen();  // refresh display
    }
#endif

    if (machineState == kPidOffline || machineState == kSensorError || machineState == kEmergencyStop || machineState == kEepromError || brewPIDdisabled) {
        if (pidMode == 1) {
            // Force PID shutdown
            pidMode = 0;
            bPID.SetMode(pidMode);
            pidOutput = 0;
            digitalWrite(PINHEATER, LOW);  // Stop heating
        }
    } else {  // no sensorerror, no pid off or no Emergency Stop
        if (pidMode == 0) {
            pidMode = 1;
            bPID.SetMode(pidMode);
        }
    }

    // Set PID if first start of machine detected, and no steamON
    if ((machineState == kInit || machineState == kColdStart || machineState == kBelowSetPoint)) {
        if (usePonM) {
            if (startTn != 0) {
                startKi = startKp / startTn;
            } else {
                startKi = 0;
            }

            if (lastmachinestatepid != machineState) {
                debugPrintf("new PID-Values: P=%.1f  I=%.1f  D=%.1f\n", startKp, startKi, 0.0);
                lastmachinestatepid = machineState;
            }

            bPID.SetTunings(startKp, startKi, 0, P_ON_M);
        } else {
            setNormalPIDTunings();
        }
    }

    if (machineState == kPidNormal) {
        setNormalPIDTunings();
        coldstart = false;
    }

    // BD PID
    if (machineState >= kBrew && machineState <= kBrewDetectionTrailing) {
        if (BREWPID_DELAY > 0 && timeBrewed > 0 && timeBrewed < BREWPID_DELAY*1000) {
            //disable PID for BREWPID_DELAY seconds, enable PID again with new tunings after that
            if (!brewPIDdisabled) {
                brewPIDdisabled = true;
                bPID.SetMode(MANUAL);
                debugPrintf("disabled PID, waiting for %d seconds before enabling PID again\n", BREWPID_DELAY);
            }
        } else {
            if (brewPIDdisabled) {
                //enable PID again
                bPID.SetMode(AUTOMATIC);
                brewPIDdisabled = false;
                debugPrintln("Enabled PID again after delay");
            }

            if (useBDPID) {
                setBDPIDTunings();
            } else {
                setNormalPIDTunings();
            }
        }
    }

    // Steam on
    if (machineState == kSteam) {
        if (lastmachinestatepid != machineState) {
            debugPrintf("new PID-Values: P=%.1f  I=%.1f  D=%.1f\n", 150.0, 0.0, 0.0);
            lastmachinestatepid = machineState;
        }

        bPID.SetTunings(steamKp, 0, 0, 1);
    }

    // chill-mode after steam
    if (machineState == kCoolDown) {
        switch (machine) {
            case QuickMill:
                aggbKp = 150;
                aggbKi = 0;
                aggbKd = 0;
                break;

            default:
                // calc ki, kd
                if (aggbTn != 0) {
                    aggbKi = aggbKp / aggbTn;
                } else {
                    aggbKi = 0;
                }

                aggbKd = aggbTv * aggbKp;
        }

        if (lastmachinestatepid != machineState) {
            debugPrintf("new PID-Values: P=%.1f  I=%.1f  D=%.1f\n", aggbKp, aggbKi, aggbKd);
            lastmachinestatepid = machineState;
        }
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

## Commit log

2026-06-13 ADD: Rancillio-Pid Clever Coffe Release v3.3.0-esp8266
    [BOM_Esp8266_4layer_rev4-3und5volt_display_20181022220223.xlsx, ESP32_DEV_BOARD_REV0_PINOUT_BOM.xlsx, PIN-Belegung.xlsx]
2026-06-13 ADD: Create detailed setup guide for Rancilio Silvia PID conversion with ESP8266
2026-06-13 Add soldermask files for Rev 1.2 and remove sample user configuration
    - Created new Gerber files for soldermask bottom and top layers in Rev 1.2 design.
    - Added Rev 1.2 layout file.
    - Deleted obsolete userConfig_sample.h file.
    [Rev_1.2.drl, Rev_1.2_copper_bottom.gbr, Rev_1.2_copper_top.gbr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]
2026-06-14 Add temperature sensor datasheet image to documentation
